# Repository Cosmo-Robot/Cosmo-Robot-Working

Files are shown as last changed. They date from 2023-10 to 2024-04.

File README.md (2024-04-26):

<h1>Cosmo Robot</h1>

<!-- ![Cosmo Robot](Images/in_operation.jpg) -->
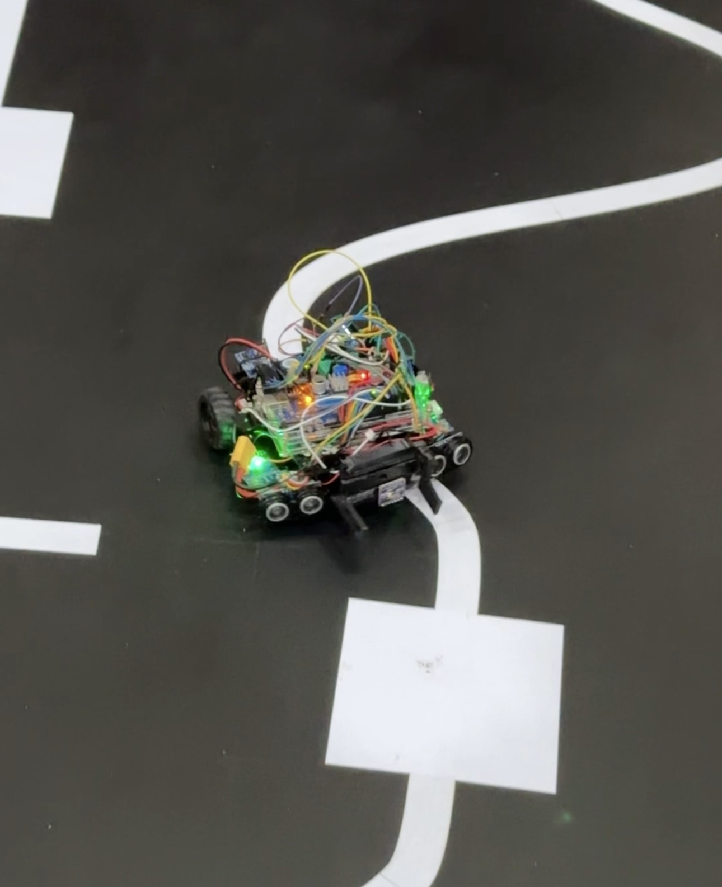
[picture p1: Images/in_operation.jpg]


<h2>Project Summary</h2>

  <p>This project was based on Arduino Mega 2560 and developed for the robot competition held under the Semester 3 module EN2533: Robot Design and Competition. "Cosmo" robot is designed to showcase various capabilities, including precise line following, obstacle avoidance during line following, navigating ramps at 20 - 30 degrees, interacting with objects using a mechanical arm, sound sensitivity, color detection, and maze-solving capabilities. Additionally, it was programmed to avoid other robots in the arena such as the guard robot, on its way to the final destination.</p>

https://github.com/Cosmo-Robot/Cosmo-Robot-Working/assets/111054736/55ebefc1-eb35-40b0-912c-31b81b9e3f68

  <h2>Features</h2>

  <ul>
      <li>Precise line following.</li>
      <li>Obstacle avoidance during line following.</li>
      <li>Ramp navigation (20 - 30 degrees).</li>
      <li>Mechanical arm for interacting with objects.</li>
      <li>Sound sensitivity.</li>
      <li>Color detection.</li>
      <li>Maze solving capabilities.</li>
      <li>Avoiding other robots (Guard Robot).</li>
  </ul>

  <h2>Components Used</h2>

  <ul>
      <li>Arduino Mega 2560.</li>
      <li>Aptinex Reykha IR array and additional IR sensor modules.</li>
      <li>100RPM N20 motors.</li>
      <li>L298 motor driver.</li>
      <li>HY-SRF05 ultrasonic sensors.</li>
      <li>VL53L0X Time-Of-Flight (TOF) sensor.</li>
      <li>TCS3472 RGB color sensor.</li>
      <li>Sound (decibel) sensor.</li>
      <li>3D printed mechanical arm with MG90 metal servo motor.</li>
  </ul>

  <h2>Design Process</h2>

  <ul>
    <li>VS Code and Arduino IDE for programming the robot in C++ language.</li>
    <li>Blender and SOLIDWORKS for robot structure and chassis design.</li>
  </ul>

 <h2>Capable Tasks of the Robot </h2>

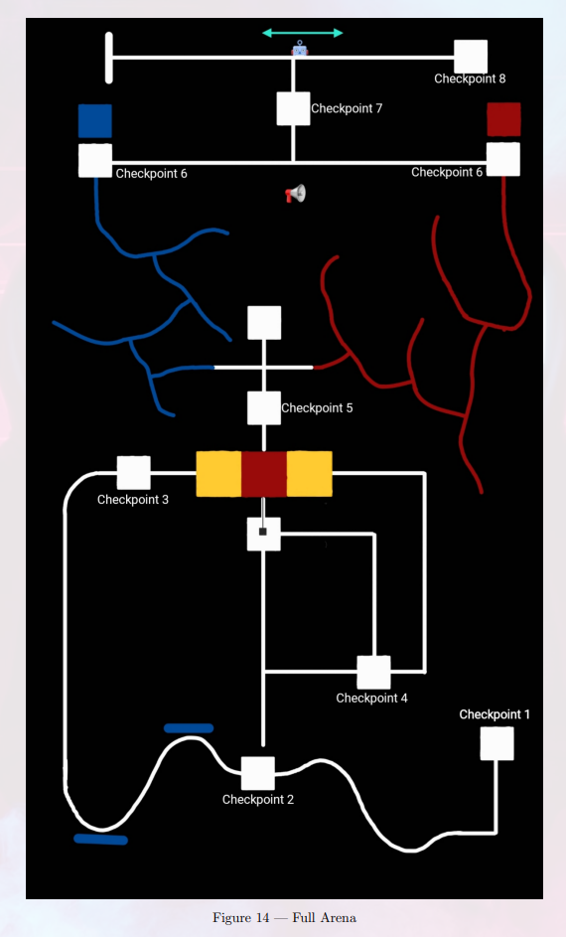
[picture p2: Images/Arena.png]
  

1. Robot will commence it's journey from the designated starting location.
2. If you are unable to complete the task by starting from the designated starting location,
you can start from a checkpoint that is not the designated starting checkpoint with a
penalty.
3. While following the line, the robot shouldn’t collide with any object that isn’t specifically
mentioned in the document.
4. When the robot is navigating from checkpoint - 3 to checkpoint - 4, it must go over the
bridge section and follow the line afterward. There will be a line on the bridge, as well.
5. You can use any mechanism to find the path to reach checkpoint - 5.
6. Pick and place the colored box in the relevant colored space.
7. The robot should freeze when sounds emit from the sound tower.
8. The robot shouldn’t collide with the guard robot.
9. The game is considered finished when the robot completes all six sub tasks, sequentially.

<h2> Game Field (Arena) Specifications </h2>

1. The game arena is characterized by dimensions of 8 feet by 8 feet as shown in figure 14.
2. Within the arena, you will find two sections dedicated to line following, obstacles avoiding,
motion with a buzzer’s sound, a bridge, a robot guard moving section, a designated starting
point, and a specified stopping point.
3. The area designated for line following and obstacles avoiding is marked by white lines, 30
mm in width, on a non-reflective matte black surface.
4. The square boxes (which may not always be positioned at the center) are 5 cm by 5 cm
in size.
5. White squares and colored squares, located on the floor are 15 cm by 15 cm in size.
6. The wall/obstacle has a height of 10 cm and is colored white.
7. Specific dimensions for the bridge section are included in the figure 12 (length measurements are in centimeters ).
8. The wording ”checkpoint X” will not be on the arena. They are shown in the figures just
for understanding purposes, only.

<h2>Robot Specifications </h2>

1. Autonomous Operation: The robot must operate entirely autonomously. Once the
robot initiates its actions, team members are prohibited from making any contact with it.
2. Robot Dimensions: The robot’s dimensions should enable it to fit comfortably within a
250mm x 250mm box (length x width). There are no height restrictions. The robot must
be started using a single onboard switch. Teams may use separate switches for restarting
and for starting from checkpoints, which must be presented to the judges prior to the run.
3. Stability Requirement: The robot must demonstrate stability and stand independently
at the starting zone when the race begins. Failure to meet this criterion will result in
disqualification.
4. Expanding Mechanism: The robot is allowed to expand during its run as long as no
damage is inflicted on the arena. It is strictly prohibited to leave behind any parts or marks
while moving within the arena. Non-compliance will lead to potential disqualification for
the team.
5. Unity of the Bot: The robot cannot split into multiple units during gameplay. Any
machines or units that are in contact with each other or are within the start zone will be
considered as a single entity.
6. Use of Components: Teams are permitted to utilize pre-made microcontroller boards
and sensor kits. However, the incorporation of wireless modules, ready-made Lego kits,
or similar assemblies are not allowed. The use of off-the-shelf kits is prohibited.
7. Simple Starting Procedure: The robot’s starting procedure should be straightforward
and devoid of any manual force or directional impuls
  
  <h2>Contributing</h2>

  <p>Feel free to contribute to the project by submitting bug reports, feature requests, or pull requests. Your contributions are highly appreciated!</p>

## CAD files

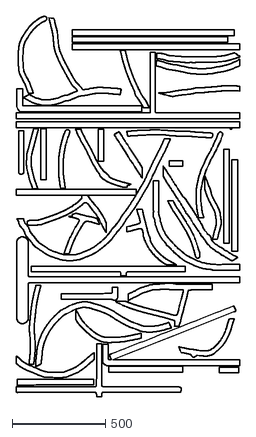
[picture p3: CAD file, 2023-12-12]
Physical Structure Design/Arena.dxf
1200.0 x 2040.8

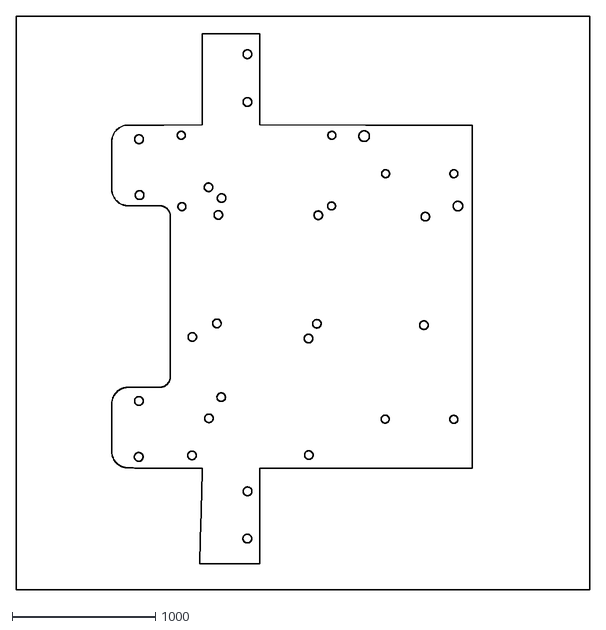
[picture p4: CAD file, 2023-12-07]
Physical Structure Design/Bottom_Panel.dxf
4000.0 x 4000.0

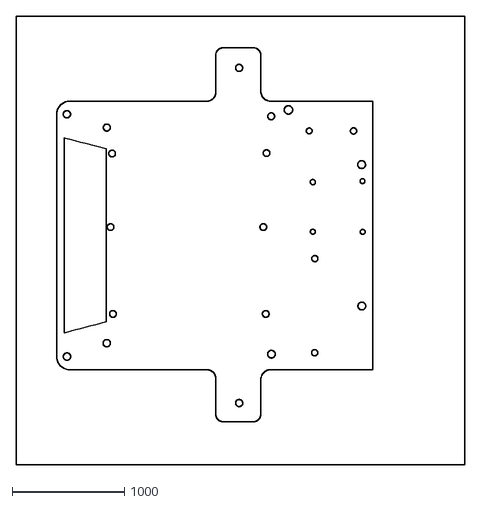
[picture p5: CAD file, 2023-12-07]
Physical Structure Design/Top_Panel.dxf
4000.0 x 4000.0

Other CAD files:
Evaluations/Exercises/Exercise 3/Robot.SLDDRW

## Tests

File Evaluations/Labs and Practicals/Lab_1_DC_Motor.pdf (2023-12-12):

Department of Electronic and Telecommunication Engineering, University of Moratuwa

EN2532 Robot Design and Competition Laboratory Sheet-Practical No: 1

Indexes: 210069F,210174X,210258J,210542B | | | Date: 07 10 2023 | | / | /………
Name: Cosmo | | | Group No: 6 | |
1. What does PWM stand for? Pulse Width Modulation
2. Main parameters to consider generating a PWM? Frequency Duty cycle Resolution
3. Describe the importance of selecting the PWM Frequency The PWM frequency influences the motor sound and the power transistor's switching speed. The human ear can hear 20Hz - 20000Hz range and typically frequencies above 16kHz is not audible. So, it should be selected to be greater than 16kHz. As the motor actually turns on and off at the PWM frequency, if that frequency is above the human audible range (at least above 16kHz), humming sounds generated can be reduced.
4. What will happen when we change the PWM Duty cycle? The speed of the motor changes proportionally to the duty cycle of the PWM signal.
5. What are the two type encoders? Relative encoders, Absolute encoders

6. Why closed loop designs are heavily used in motor controlling Because it gives the ability to regulate the motor parameters such as motor speed, torque and direction of rotation etc. by enabling some sort of intelligence in the system to enhance the system stability.
7. List down the modules(sensors) which can be used to get following feedbacks from a DC motor
a. Rotation speed Encoders, Stroboscopes, Tachometers
b. Direction of rotation Encoders (with two outputs with phase offset)
c. Torque Strain-Gauge sensors
8. If the PWM frequency is 5khz and duty cycle resolution is 10bit. Sketch the PWM signal when duty cycle value is set to 511 in a specific micro controller.

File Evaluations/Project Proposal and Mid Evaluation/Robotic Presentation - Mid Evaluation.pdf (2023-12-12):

# Team Cosmo

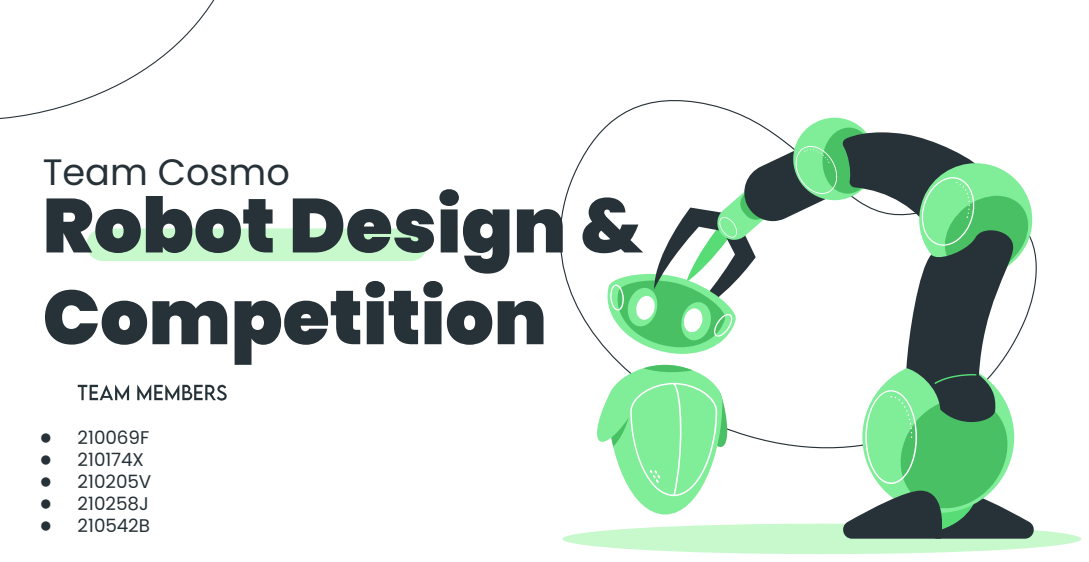
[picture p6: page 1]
Robot Design & Competition

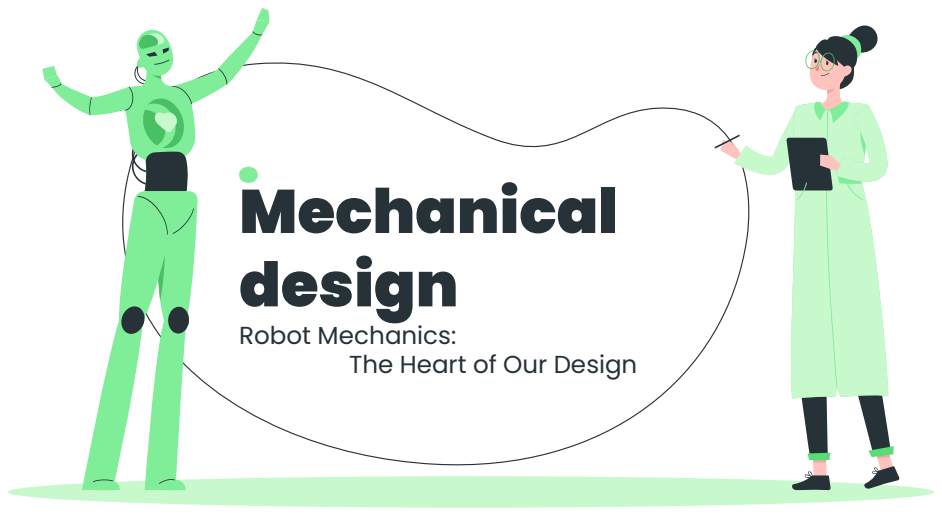
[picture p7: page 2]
Mechanical design; Robot Mechanics:

The Heart of Our Design

# Mechanical design

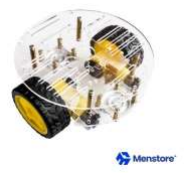
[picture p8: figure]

### 2 wheel design

robot design offers
greater agility and
simplicity, reducing cost
and complexity
compared to four-wheel
designs with wheel
encoders.

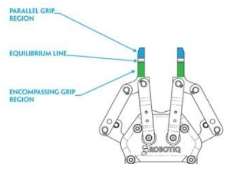
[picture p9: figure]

### Mechanical arm

Mechanical arms on two-wheel robots enable precise manipulation, enhancing
adaptability for various
tasks, making them
preferable.

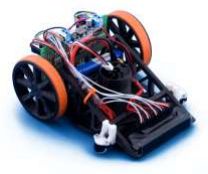
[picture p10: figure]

### 2 supporting wheels

Our 2-wheel robot
design features 2 front
supporting wheels,
preventing collisions
during the slope-climbing phase.

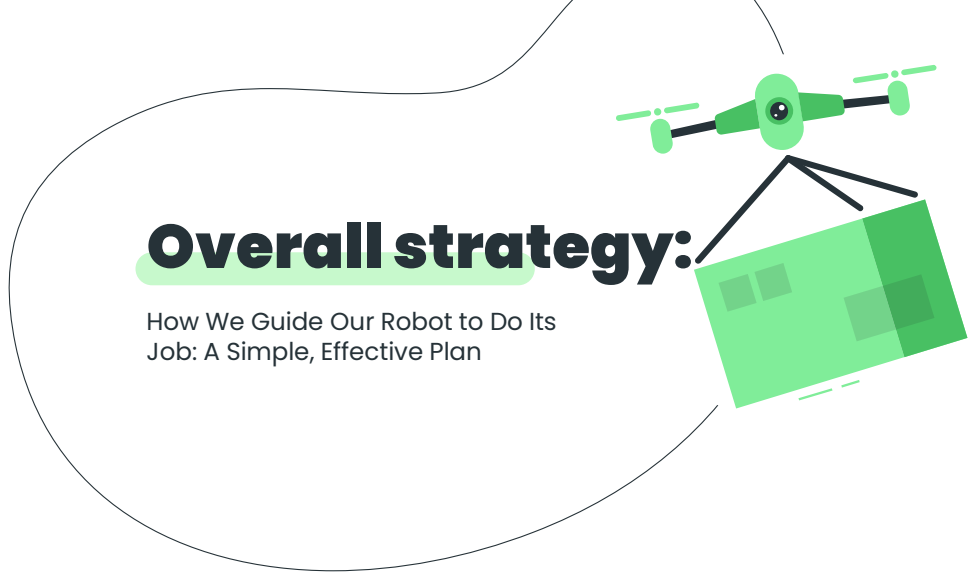
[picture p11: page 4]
Overall strategy:

How We Guide Our Robot to Do Its
Job: A Simple, Effective Plan

# Overall strategy:

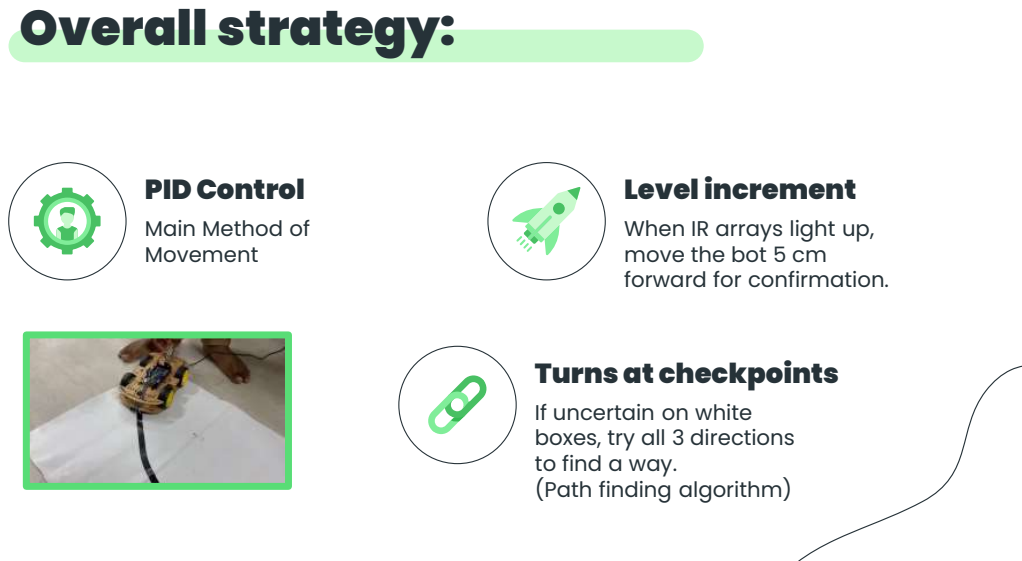
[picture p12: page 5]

PID Control
Main Method of
Movement

Level increment
When IR arrays light up,
move the bot 5 cm
forward for confirmation.

Turns at checkpoints
If uncertain on white
boxes, try all 3 directions
to find a way.
(Path finding algorithm)

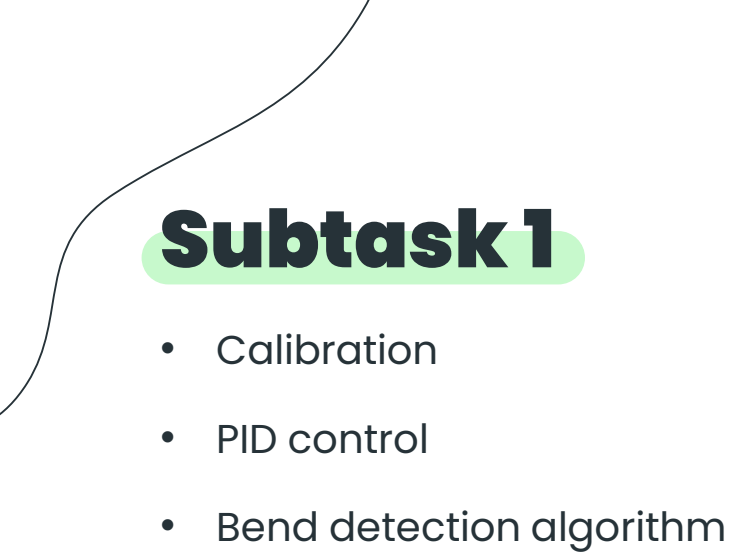
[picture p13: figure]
• Calibration; • PID control; • Bend detection algorithm; Subtask 1
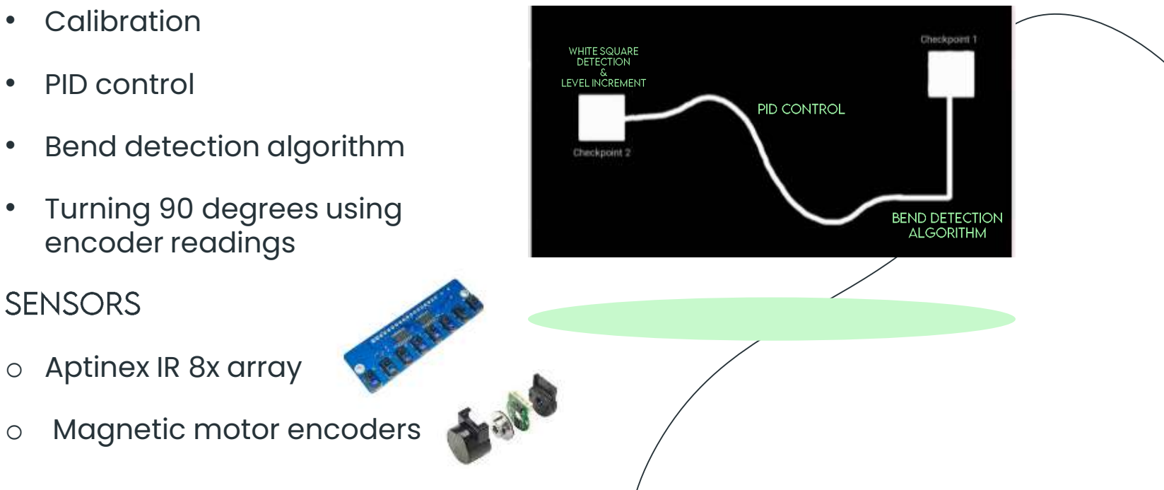
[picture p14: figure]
• Turning 90 degrees using encoder readings; • Aptinex IR 8x array; • Magnetic motor encoders

- PID control

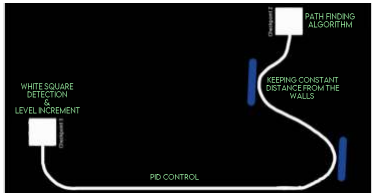
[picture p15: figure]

- Distance sensors at the front to detect the walls
- Distance sensors at the side to keep a constant distance from walls
- Sharp IR sensors
- Ultrasonic sensors/ToF(Time of Flight) sensors

# Subtask 2

• Turning off all non-using sensors; • Angle measuring sensors to move straight on the ramp + wheel encoders for straight movements; Subtask 3 - A
• Using IR array readings in case the robot moved out of the ramp; • Gyroscope (MPU6050)

# Subtask 3 - B


- Algorithm to detect T junction
- Use predefined lengths to move to desired locations
- Mechanical arm to grab the object (which can slide up at idle)
- Grabbing the object and pulling back with the arm, travelling across pre-defined bends
- Sharp IR sensor
- Servo based joints

• Cross junction detection algorithm; • Distance sensor to identify the box and color sensor to scan color; • Node tree algorithm to traverse through the maze; Subtask 4
• Analog IR readings to detect blue and red lines; • Unloading the load using predefined lengths (encoder readings); • Home-made color sensor (LEDs and LDR)

• Sound sensor to trigger movements; • Deciding the direction to turn by pre-chosen color; • Bend detection algorithm; • Sound sensor; Subtask 5

• Front sharp IRs to detect the movement direction of the guard robot; Subtask 6

- Bend detection
- Sharp-IR sensors

# Task delegation

Yasiru Mechanical Design, Maze Traversal and Navigation; Hasitha Mechanical Arm design and implementation, Algorithm development
Linuka Sensor implementation, simulation, Documentation and Reporting; Circuit implementation, Algorithm refinements, Troubleshooting and Debugging; Lasith Algorithm development, PCB design, Battery and Power Management

### Kavindu

Thanks!

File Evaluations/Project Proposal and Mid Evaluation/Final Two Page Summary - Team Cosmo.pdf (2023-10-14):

# Two Page Summary

Team Name: Cosmo

## 1 Overall Strategy

### 1.1 Sub Task 01

Our robot relies on a precise IR sensor panel comprising eight transmitter and receiver pairs to track a white line on a black surface. The middle two sensors detect the white line, while the other three sensors on the left monitor the left side, and the remaining sensors on the right monitor the right side. Using a PID control algorithm, our robot adjusts motor speeds based on sensor inputs, ensuring smooth navigation back to the white line and we utilize magnetic encoders to navigate 90-degree bend with precise accuracy.

### 1.2 Sub Task 02

This task is accomplished through the use of Sharp IR sensors. If two sensors at the front side of the bot detect the wall, the bot is gently turned to maintain a consistent distance between the wall and the ultrasonic sensor on the corresponding side of the bot (either left or right based on the detected wall side). This adjustment continues until the bot realigns with the line. The remaining adjustments are handled by the PID control algorithm.

### 1.3 Sub Task 03

Firstly, unnecessary sensors are turned off to conserve torque. We use a gyroscope to measure the angle, ensuring the robot moves straight on the ramp in the absence of the line. When the robot reaches the top of the ramp, an IR array can detect whether the robot has moved out of the platform, while encoders maintain the straight movement. The algorithm guides the robot to the checkpoint 4 through known bends.
After reaching checkpoint 4, the algorithm detects the T-junction and utilizes predefined distances to navigate to specific locations. i.e., after reaching the T-junction, the robot takes a right turn and moves forward for a known distance with the assistance of IR sensors until it reaches the object. Once the object is within range, the mechanical arm grabs it and pulls back approximately 55 cm before releasing it. Subsequently, the robot moves backward until it detects the junction and then takes a right turn, making necessary adjustments, and continues moving until it reaches checkpoint 5.

### 1.4 Sub Task 04

We implement a cross-junction detection algorithm to identify cross-junctions, and the robot recognizes boxes using distance sensors. Using a color sensor, the robot can scan and detect colors. Upon returning to the cross-junction, the robot determines a suitable path based on the identified color using the color sensor. We employ a node tree algorithm to traverse through the maze and the robot uses analog IR readings to detect blue and red lines. Traversal stops when the white box is detected. To unload the colored box, the robot moves forward a known distance and then returns to its original position.

### 1.5 Sub Task 05

The robot is equipped with a sound sensor to trigger the movements. It determines the direction to turn based on a pre-selected color. When a sound is detected using the sound sensor, the robot freezes. Conversely, in the absence of sound, the robot moves forward. Using this approach, the robot takes turns based on bend detection algorithms and continues moving until it reaches checkpoint 7.

1

### 1.6 Sub Task 06

The robot will wait at the checkpoint until the guard robot’s movements are detected by the distance sensors. It utilizes the trigger time of the two sensors to identify the direction in which the guard robot moved. After detecting that the guard robot moved to the left side, the robot initiates its movements. It continues moving until a junction is encountered, then takes a right turn and moves until it reaches the final destination.

## 2 Robot Mechanical Design


Figure 1: Mechanical Arm


Figure 2: Two Wheel Design and Two Supporting Wheels

## 3 Task Delegation

- B.Y.N. Basnayake - Mechanical Design, Maze Traversal and Navigation
- M.M.H.H.B. Gallella - Mechanical Arm design and Implementation, Algorithm Development
- H.L.N.B. Haputhanthri - Algorithm Development, PCB design, Battery, and Power Management
- R.M.K.C. Jayathissa - Circuit Implemntation, Algorithm Refinements, Troubleshooting and Debugging
- R.M.L.H. Ratnayake - Sensor Implementation, Simulation, Documentation and Reporting

2

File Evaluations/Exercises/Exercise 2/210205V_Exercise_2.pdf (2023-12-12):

Index:210205V
Team: Cosmo
Module: EN2533
Exersise 2

## The Arduino Mega 2560 Board

The Arduino Mega 2560 Board is a very powerful board that is a versatile platform for electronics and microcontroller projects. Let's explore its key features and functions.


### 1. Power Supply:

The power supply in the Arduino Mega 2560 Board is responsible for providing stable voltage and current to the board and its connected components. It primarily comprises a voltage regulator and a power connector.

- Voltage Regulator: At the core of this subsystem is the voltage regulator, often the LM7805. This component is crucial for regulating the input voltage, typically ranging from 7V to 12V, down to a stable 5V supply. This stable voltage ensures that the microcontroller unit (MCU) and other components operate reliably.
- Power Connector: The power connector, including the power jack and Vin pin, serves as the interface for connecting external power sources. Users can connect batteries or external power supplies to these connectors.

### 2. Microcontroller Unit (MCU):

The MCU subsystem is the heart of the Arduino Mega 2560 Board and is responsible for executing user programs. At its core is the ATmega2560 microcontroller.

ATmega2560 Microcontroller: This powerful microcontroller is equipped with a wide range of digital and analog I/O pins, generous program memory (Flash), SRAM, and EEPROM. Its robust processing capabilities make it suitable for various applications. It is responsible for executing user-written code, processing inputs, and generating outputs.

### 3. Communication Interfaces:

Effective communication with external devices and peripherals is facilitated by the communication interfaces subsystem. It encompasses multiple components that enable seamless data exchange.
- USB Interface: The board features a USB-to-Serial converter, often the Atmega16U2, which acts as a bridge between the USB connection and the microcontroller. This component facilitates USB communication between the Arduino and a computer, allowing users to program and monitor the board.
- Serial Ports: The Arduino Mega 2560 includes multiple hardware UART ports, offering reliable serial communication capabilities. These ports are often used for communication with various external devices, such as sensors, displays, or other microcontrollers.

### 4. Various Peripheral Components:

- Crystal Oscillator: A crystal oscillator provides precise clock signals to the MCU, ensuring accurate timing for program execution.
- LEDs: Light Emitting Diodes (LEDs) are integrated for visual feedback and debugging. They are often used to indicate the board's status, such as power and activity.
- Reset Button: The reset button serves as a user interface element, allowing users to restart the MCU when needed, which is particularly useful during programming and debugging.

### 5. Pins

- Digital Pins: The Arduino Mega 2560 Board features 54 digital pins, labeled from 0 to 53. They are commonly used for tasks such as reading digital sensors and interfacing with other digital devices.
- Analog Pins: The board includes 16 analog pins, labeled from A0 to A15. These pins are primarily used for reading analog signals from sensors. They can also be configured as digital I/O pins.
- Power Pins: There are 3 types of power pins. 3.3V, 5V, and Vin for an external power source.
- Ground Pins: Ground pins (labeled GND) provide a common reference point for electrical circuits. There are 5 ground pins.
- Reset Pin: The Reset pin is used to reset the microcontroller.
- Communication Pins: It has four hardware UART pins for serial communication
- PWM Pins: The board includes a set of pins that support Pulse Width Modulation (PWM). These pins can generate PWM Signals. The PWM pins are often used for controlling the brightness of LEDs and the speed of motors.
- External Interrupt Pins: There are a total of six external interrupt pins. These pins allow the board to react to external events by triggering an interrupt service routine.

Resources: https://docs.arduino.cc/resources/datasheets/A000067-datasheet.pdf

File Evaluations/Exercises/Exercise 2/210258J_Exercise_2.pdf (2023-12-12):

# Arduino MEGA 2560

210258J - R.M.K.C. Jayathissa - Team Name: Cosmo

The Arduino Mega 2560 is a powerful development board designed for extensive applications. It features the ATmega2560 microcontroller running at 16 MHz and offers 54 digital I/O pins, 16 analog inputs, 4 UARTs (hardware serial ports), a USB connection, power jack, ICSP header, and a reset button. Widely utilized in projects such as robotics and automation, its generous memory, diverse I/O capabilities, and strong community backing make it a top choice among electronics enthusiasts and developers.


Figure 1: Arduino MEGA 2560 Rev3

## 1 Micro Controller Unit (MCU)

The Arduino microcontroller unit (MCU) is the brain behind Arduino boards, responsible for executing user programs. In the Arduino Mega 2560, the core MCU is the ATmega2560. It processes instructions, enabling the board to interact with various components, making it versatile for a wide range of projects.

### 1.1 ATmega2560 Microcontroller

The ATmega2560 microcontroller is a key component in the Arduino Mega 2560 board. It is an 8-bit microcontroller based on the AVR RISC architecture. Running at a clock speed of 16 MHz, the ATmega2560 offers 256 KB of flash memory for program storage, 8 KB of SRAM for data storage, and 4 KB of EEPROM for non-volatile data storage.
This microcontroller provides 54 digital input/output pins, 16 analog inputs, and multiple communication interfaces, including UART, SPI, and I2C. Its robust capabilities make it suitable for a wide range of applications, from robotics and automation to data acquisition and control systems.

## 2 Power Supply

### 2.1 External Power Supply

This option allows users to connect an external power source within the specified voltage range, enabling the board to function without relying on USB power.

1

### 2.2 Voltage Regulator

The Arduino board has a built-in voltage regulator that keeps the voltage stable, ensuring consistent power to the board’s components. It regulates the incoming power supply to the required voltage for smooth operation.

## 3 Communication Interfaces

### 3.1 USB Interface

The Arduino board has a built-in USB-to-serial converter (ATmega16U2) for programming and computer communication via USB.

### 3.2 Serial Ports

Multiple UART ports enable easy serial communication with external devices, enhancing data exchange capabilities.

## 4 Input and Output Peripherals

### 4.1 Analog Input/Outputs

- Analog Pins - The Arduino board has 16 analog pins, labeled from A0 to A15 for reading continuous voltage signals from sensors.
- PWM Pins - With 15 PWM (Pulse Width Modulation) pins, the board can control devices like motors and LEDs with varying intensity or speed.

### 4.2 Digital Input/Outputs

The Arduino Mega 2560 Board provides 54 digital pins, labeled from 0 to 53 primarily used for reading digital sensors and interfacing with other digital devices.

## 5 Other Peripheral Components

### 5.1 Crystal Oscillator

The crystal oscillator delivers accurate clock signals to the MCU, guaranteeing precise timing for program execution.

### 5.2 LEDs (Power LED, Tx and Rx LEDs etc.)

The LEDs integrated into the Arduino Mega 2560 board serve as vital indicators, displaying essential information such as power status, board activity, and debugging feedback

### 5.3 Reset Button

This button on the Arduino board allows users to restart the microcontroller, enabling the board to return to its initial state and initiate new program uploads or debugging sessions.

References :
(https://scholar.ppu.edu/bitstream/handle/123456789/638/1.pdf?sequence=3&isAllowed=
y) (https://scholar.ppu.edu/bitstream/handle/123456789/638/1.pdf?sequence=3&isAllowed=y)
(https://docs.arduino.cc/resources/datasheets/A000067-datasheet.pdf)

2

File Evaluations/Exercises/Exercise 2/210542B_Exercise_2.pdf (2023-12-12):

## Arduino Mega 2560: Subsystems, Peripheral Circuitry, and Components

210542B - Ratnayake R.M.L.H.

## 1 Introduction

Arduino Mega 2560 is a powerful micro-controller board in the Arduino family that is widely used in robotics among with many other fields. With main focus to the Rev3 edition of the board, this report discusses about the different subsystems present in the board along with the peripheral circuitry and components.

## 2 Main Subsystems of Arduino Mega 2560

### 2.1 Power Subsystem

The board can be powered in various ways such as through the USB
cable, | power jack or the Vin | in-
put. | Voltage regulators are used to
give the ATmega2560 micro-controller and other components with their required voltage, and a 3.3V output.

The Arduino board has 3.3V, 5V pins to provide power to the externally connected components along with 5 ground (GND) pins.


Connector | Voltage Range | Component Used
USB Vin PWRIN (DC jack) | 4.8V - 5.5V 5V 7V - 12V | -LMV358LIST-A.9 Op-Amp SPX1117M3-L-5-0 Regulator

### 2.2 Communication Subsystem

ATmega16U2

This chip acts as an interface between the ATmega2560 and the USB input signals. It is a USB-to-Serial converter acting as a bridge between the USB port of the computer and the serial ports of the micro-controller. It enables the user to program the micro-controller easily and get data back from the board as well.

I2C Ports

In Arduino Mega2560, pins 20 and 21 act as I2C (Inter-Integrated Circuits) pins. Multiple I2C devices can be simultaneously connected to these ports to communicate using the I2C protocol. LCD displays are one example.

1

UART Ports

Arduino Mega2560 consists of 4 UART (Universal Asynchronous Receiver/ Transmitter) serial ports. These ports enables to communicate with some external devices like GPS and RFID modules.

SPI Ports

Arduino Mega2560 has 4 SPI (Serial Peripheral Interface) pins, 50, 51, 52, and 53, for quicker communication with peripheral devices within short distances.

### 2.3 Micro-Controller Unit (MCU)

ATmega2560

ATmega2560 micro-controller sits as the core of all performances of the board. It works up to 16 MIPS at 16MHz clock speed (which is provided by a separate crystal oscillator on the board) and consists of 256KB ROM, 4KB EEPROM, 8KB SRAM and 32 x 8 general purpose registers.

Crystal Oscillator

A 16MHz crystal oscillator is fixed in the board to provide the micro-controller with accurate clock signals to work properly.

### 2.4 Input Output (I/O) Subsystem

The Arduino Mega2560 board comprises with 54 digital I/O pins of which 15 are capable of generating PWM signals, and 16 analog pins.

Other than that, there are 6 interrupt pins, 2, 3, 18, 19, 20, 21. When a peripheral connected to these pins triggers an interrupt, the processor will immediately stops whatever it is currently doing an starts processing the interrupt signal.

### 2.5 Other Components

LEDs

Three types of LEDs are visible in Arduino Mega2560 board, namely the power LED, two Tx/ Rx LEDs, and the LED on pin 13.

RESET Button

By pressing this button, the program that is running on the micro-controller can be reset to its beginning.

## References


https://docs.arduino.cc/resources/datasheets/A000067-datasheet.pdfhttps://www.electronicshub.org/arduino-mega-pinout/

2

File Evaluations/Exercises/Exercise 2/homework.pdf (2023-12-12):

- Study the Arduino Mega 2560 Board and describe the functionality of its peripheral circuitry
➢Identify the subsystems
➢Explain the purpose of different electronic components inside each subsystem
Submit a report (pdf): page limit 2 (no cover page needed)

# Homework




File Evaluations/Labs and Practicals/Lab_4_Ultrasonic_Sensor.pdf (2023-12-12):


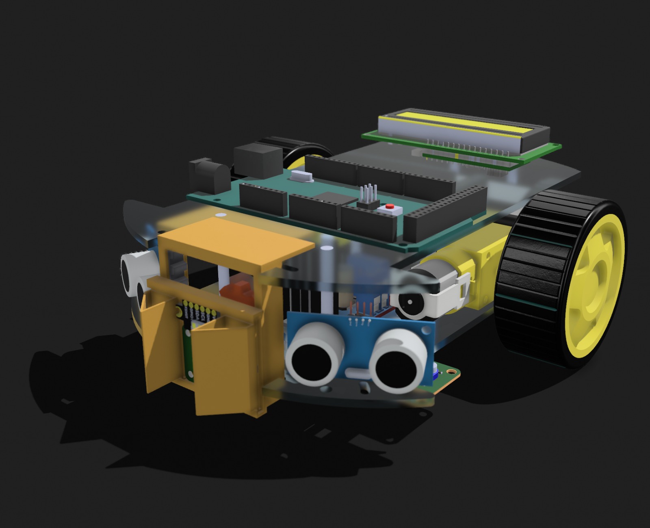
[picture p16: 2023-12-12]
Evaluations/Exercises/Exercise 3/Robot 3D.jpg

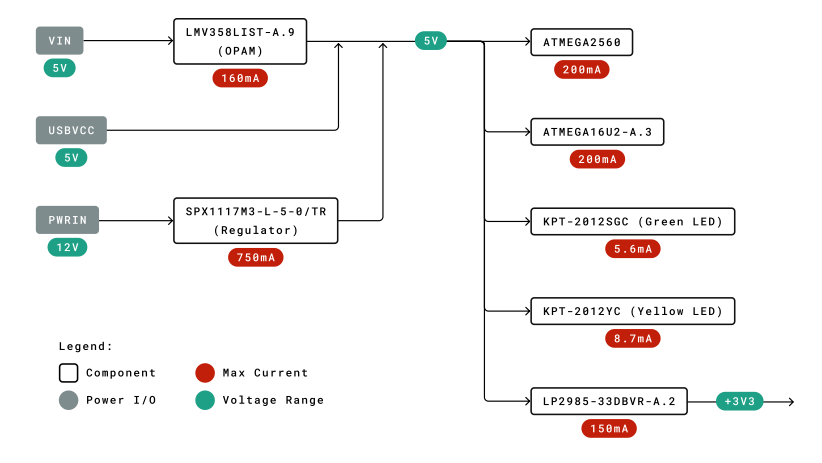
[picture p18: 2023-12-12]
Evaluations/Exercises/Exercise 2/power.png

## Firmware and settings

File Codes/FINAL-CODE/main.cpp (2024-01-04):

//////////////////////////////////////////////////////////////////////////////////////////////////////////////////////////////////////////////////
//Creator:  Team Cosmo
//members: 1)Yasiru Basnayake
//         2)Kavindu Jayathissa
//         3)Lasith Haputhanthri
//         4)Linuka Ratnayake
//         5)Hasitha Gallella
//////////////////////////////////////////////////////////////////////////////////////////////////////////////////////////////////////////////////

#include <Arduino.h>
#include <EEPROM.h>
#include <Servo.h>
#include <Adafruit_I2CDevice.h> 
#include <U8g2lib.h> // include u8g2 library
#include <Wire.h>
#include "Adafruit_TCS34725.h"

// Header guard to prevent multiple inclusions
#include "line follow/lineFollow.h"
#include "detections/detections.h"
#include "sensors/sensors.h"
#include "level management/levelManage.h"

/////////////////////////////////Object Definitions///////////////////////////////////////////////////////////////////////////////////////////////

#ifdef U8X8_HAVE_HW_SPI
#include <SPI.h>
#endif
#ifdef U8X8_HAVE_HW_I2C
#include <Wire.h>
#endif

U8G2_SH1106_128X32_VISIONOX_F_HW_I2C u8g2(U8G2_R0, /* reset=*/U8X8_PIN_NONE);

Servo arm; // create servo object to control a servo

Adafruit_TCS34725 tcs = Adafruit_TCS34725();

/////////////////////////////////Definitions///////////////////////////////////////////////////////////////////////////////////////////////

#define Debug_led 13

#define trigPin 6 // define trig pin 6 and echo pin 7
#define echoPin 7

#define calibration 7 // pushbutton input for calibration

#define buzzer_pin 8 // pin for buzzer

#define right_bend_sensor 9 // pin for right bend sensor

#define IR_ARRAY_LENGTH 12 // IR_array 8 space empty array

#define ENR 3 // define right motor enable pin is 3 and left 2
#define ENL 2

#define Motor_Right_Forward 28
#define Motor_Right_Backward 24
#define Motor_Left_Forward 22
#define Motor_Left_Backward 26

#define RIGHT_MOTOR 1 // Motor and Direction Definitions
#define LEFT_MOTOR 2
#define FORWARD 1
#define BACKWARD 2

#define SOUND_SENSOR A10 // Sound sensor
#define SOUND_THRESHOLD 300
#define SOUND_WAIT_TIME 500 // milliseconds
#define SOUND_LED 13

#define SENSOR_LEFT 1 // Ultrasonic sensors
#define SENSOR_RIGHT 2

#define SENSOR_LEFT_TRIG_PIN 32
#define SENSOR_LEFT_ECHO_PIN 34

#define SENSOR_RIGHT_TRIG_PIN 36
#define SENSOR_RIGHT_ECHO_PIN 38

#define MAX_ULTRASONIC_DISTANCE 30 // in centimeters

#define TASK_SWITCH 44 // Task selection switch
#define SWITCH_MSB 45
#define SWITCH_MID_SB 46
#define SWITCH_LSB 47

bool wallVar = true;
// PID parameters for Line Following
double Kp = 8;
double Ki = 0;
double Kd = 7;

// PID parameters for Ultrasonic Wall Following
double UKp = 35;
double UKi = 0;
double Ukd = 20;

int Drive_constant = 200;

// Initialize PID variables
double prevError = 0;
double integral = 0;
double derivative = 0;

// recorrect
int Ir_thresholds[] = {300, 300, 100, 100, 100, 105, 400, 400};

int prev_error_history[] = {0, 0, 0, 0, 0, 0, 0, 0, 0, 0};
int stack_pointer = 0;

int IR_history_count = 0;
int IR_history = 0;
int IR_first_grabbed = 0;

int guard_left = 0;
int guard_right = 0;
int guard_left_prev = 2;
int guard_right_prev = 2;

int count = 0;

int crossCount = 0;

bool pull_box_arm_retract = false;
bool pull_bend = false;

const String LINE_COLOR = "WHITE";
int array_lit_amount = 0;
// Define the size of the array and the EEPROM address to start writing data
const int arraySize = 8;     // Adjust this based on your array size
const int eepromAddress = 0; // EEPROM address where you want to start writing

bool bend_done = false;

bool Switch = 1;

bool bend_start = false;

bool bend_condition = false;

bool boxGrabbed = false;

int now_time = 0;

bool colorBoxGrabbed = false;

String mode = "normal";
String wall_side = "";

String STAGES[] = {"LINE", "WALL", "RAMP", "PULL", "COLOR", "SOUND", "GUARD", "HALT"};
int pointer = 0;

int IR_array[IR_ARRAY_LENGTH];

int Threshold = 100;

int prev_position = 0;
int prev_history_sum = 0;

int x = 0; // bool Switch = 0; //0 for left ; 1 for right;

float ultrasonic_prev_error = 0;

int sound_threshold = 500;

int temp = 0;

int Left_drive = 0;
int Right_drive = 0;

String color_picked = "none";
bool colorBoxPlaced = true;

/////////////////////////////////Function Declarations/////////////////////////////////////////////////////////////////////////////////////

void motor(int , int);
void buzzer_beep();
void wallFollow();

//////////////////////////////////////////////////////////////////////////////////////////////////////////////////////////////////////////////////
/////////////////////////////////////////Setup//////////////////////////////////////////////////////////////////////////////////////////
/////////////////////////////////////////////////////////////////////////////////////////////////////////////////////////////////////

void setup()
{
  // put your setup code here, to run once:

  //begin serial communication
  Serial.begin(115200);
  u8g2.begin();

  if (tcs.begin()) {
    Serial.println("Found sensor");
  } else {
    Serial.println("No TCS34725 found ... check your connections");
    while (1);
  }

  soundCalibrate(); // Calibrate the sound sensor

  // pinmode trig and echo
  pinMode(trigPin, OUTPUT);
  pinMode(echoPin, INPUT);

  pinMode(buzzer_pin, OUTPUT);

  pinMode(Motor_Right_Forward, OUTPUT);
  pinMode(Motor_Right_Backward, OUTPUT);
  pinMode(Motor_Left_Forward, OUTPUT);
  pinMode(Motor_Left_Backward, OUTPUT);
  
  pinMode(right_bend_sensor, INPUT);

  pinMode(calibration, INPUT);

  pinMode(SENSOR_LEFT_ECHO_PIN, INPUT);
  pinMode(SENSOR_LEFT_TRIG_PIN, OUTPUT);
  pinMode(SENSOR_RIGHT_ECHO_PIN, INPUT);
  pinMode(SENSOR_RIGHT_TRIG_PIN, OUTPUT);

  pinMode(TASK_SWITCH, INPUT);
  pinMode(SWITCH_MSB, INPUT);
  pinMode(SWITCH_MID_SB, INPUT);
  pinMode(SWITCH_LSB, INPUT);

  pinMode(12, INPUT);

  //reading the IR thresholds from EEPROM
  for (int i = 0; i < IR_ARRAY_LENGTH; i++)
  {
    byte temp = 0;
    // Ir_thresholds[i] = EEPROM.read(i)*4;
    EEPROM.get(i, temp);
    Ir_thresholds[i] = temp;
  }

  //for motor initialization
  motor(RIGHT_MOTOR, FORWARD);
  motor(LEFT_MOTOR, FORWARD);

  modeSelect(); // Select the mode of operation
}

//////////////////////////////////////////////////////////////////////////////////////////////////////////////////////////////////////////////////
/////////////////////////////////////////Loop//////////////////////////////////////////////////////////////////////////////////////////
/////////////////////////////////////////////////////////////////////////////////////////////////////////////////////////////////////

void loop()
{

  // Automatically increment task after detecting a white square.
  levelManage();

  if (Switch != 1)
  {
    Left_drive = 0;
    Right_drive = 0;
  }

  //signalling the speed to the motors
  analogWrite(ENL, Left_drive);
  analogWrite(ENR, Right_drive);

  // put your main code here, to run repeatedly:
  if (digitalRead(calibration) == 1){calibrate();}
}

//////////////////////////////////////////////////////////////////////////////////////////////////////////////////////////////////////////////////
/////////////////////////////////////////FUNCTIONS//////////////////////////////////////////////////////////////////////////////////////////
/////////////////////////////////////////////////////////////////////////////////////////////////////////////////////////////////////

///////////////////////////Motor direction choosing///////////////////////////////////////////

void motor(int motor, int direction)
{
  if (motor == RIGHT_MOTOR)
  {
    if (direction == FORWARD)
    {
      digitalWrite(Motor_Right_Forward, HIGH);
      digitalWrite(Motor_Right_Backward, LOW);
    }
    else if (direction == BACKWARD)
    {
      digitalWrite(Motor_Right_Forward, LOW);
      digitalWrite(Motor_Right_Backward, HIGH);
    }
  }
  else if (motor == LEFT_MOTOR)
  {
    if (direction == 1)
    {
      digitalWrite(Motor_Left_Forward, HIGH);
      digitalWrite(Motor_Left_Backward, LOW);
    }
    else if (direction == BACKWARD)
    {
      digitalWrite(Motor_Left_Forward, LOW);
      digitalWrite(Motor_Left_Backward, HIGH);
    }
  }
}

///////////////////////////For debugging ///////////////////////////////////////////

void buzzer_beep()
{
  digitalWrite(buzzer_pin, 1);
  delay(100);
  digitalWrite(buzzer_pin, 0);
}

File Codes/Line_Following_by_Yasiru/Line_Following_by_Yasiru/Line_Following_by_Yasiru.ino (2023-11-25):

// THIS IS FIRST AND SIMPLEST WORKING CODE FOR CALIBERATION AND BEND TAKING

#include <Arduino.h>

#include <LiquidCrystal_I2C.h>

#include <PID_v1.h>

#include <EEPROM.h>

// Define the size of the array and the EEPROM address to start writing data
const int arraySize = 8; // Adjust this based on your array size
const int eepromAddress = 0; // EEPROM address where you want to start writing


// Define PID parameters
double Kp = 7;
double Ki = 1.5;
double Kd = 10;

// Initialize PID variables
double prevError = 0;
double integral = 0;
double derivative = 0;

//recorrect
int Ir_thresholds[] = {300, 300, 100, 100, 100, 105, 400, 400};


// Define the setpoint (center of the line)
double setpoint = 512;

// Initialize PID variables
double input, output;
PID pid(&input, &output, &setpoint, Kp, Ki, Kd, DIRECT);


LiquidCrystal_I2C lcd(0x27,20,4);  // set the LCD address to 0x27 for a 16 chars and 2 line display

//define trig pin 6 and echo pin 7
#define trigPin 6
#define echoPin 7

//pushbutton input for caliberation
#define caliberation 7

//pin for buzzer
#define buzzer_pin 8

bool swich = 1; 

int now_time = 0;

String mode = "normal";

//IR_array 8 space empty array
int IR_array[8];

int Threshold = 100;

//define right motor enable pin is 3 and left 2
#define ENR 3
#define ENL 2

#define Motor_Right_Forward 41
#define Motor_Right_Backward 43
#define Motor_Left_Forward 45
#define Motor_Left_Backward 47

// defines variables
long duration;
int distance;

// bool Switch = 0; //0 for left ; 1 for right;
int x = 0;

void motor(int motor, int direction);
void caliberate();
void buzzer_beep();
void LCD_initial();

void setup() {

  pinMode(buzzer_pin, OUTPUT);

  //pin 8 is buzzer, tur it on and off for 2 quick beeps
  buzzer_beep();
  delay(100);
  buzzer_beep();
  

  lcd.init(); // initialize the lcd 
  // Print a message to the LCD.
  lcd.backlight();

  LCD_initial();

  //pinmode trig and echo
  pinMode(trigPin, OUTPUT);
  pinMode(echoPin, INPUT);

  //Serial begin
  Serial.begin(9600);

  for (int i = 0; i < 8; i++) {
    Ir_thresholds[i] = EEPROM.read(i)*4;
  }

  Serial.print("int IR_thresholds[] = {");
  for (int i = 0; i < 8; i++){
    Serial.print(Ir_thresholds[i]);
    Serial.print(", ");
  }
  Serial.println("};    ");


  pinMode(Motor_Right_Forward, OUTPUT);
  pinMode(Motor_Right_Backward, OUTPUT);
  pinMode(Motor_Left_Forward, OUTPUT);
  pinMode(Motor_Left_Backward, OUTPUT);


  // Initialize the PID controller
  pid.SetMode(AUTOMATIC);
  pid.SetOutputLimits(-255, 255); // Adjust these limits according to your motor driver

  // Start the PID controller
  pid.SetSampleTime(10); // Update the PID every 10ms



  // digitalWrite(Motor_Right_Forward,1);

  motor(1,1);
  motor(2,1);

  pinMode(caliberation, INPUT);
  
}

int temp = 0;

void loop() {

  if (digitalRead(caliberation) == 1){
    caliberate();
  }


  //serial print from A0 to A7
   for (int i = 0; i < 8; i++){
    // Serial.print(analogRead(i));
    // Serial.print(" ");
    if (analogRead(i) > Ir_thresholds[i]){
      temp = 1;}
    else{
      temp = 0;}
     IR_array[i] = temp;

   }

//  for (int i = 0; i < 8; i++){
//    Serial.print(IR_array[i]);
//    Serial.print(" ");
//   }
  // Serial.println(" ");

  int array_lit_amount = IR_array[0] + IR_array[1] + IR_array[2] + IR_array[3] + IR_array[4] + IR_array[5] + IR_array[6] + IR_array[7];
  int left_sum = -4*IR_array[0] -3*IR_array[1] -2*IR_array[2] -1*IR_array[3];
  int right_sum = 1*IR_array[4] +2*IR_array[5] +3*IR_array[6] +4*IR_array[7];
  int position = left_sum + right_sum;

   derivative = position - prevError;

  int PID_constant = position*Kp + Kd * derivative;

  prevError = position;

  
  //Serial.println(position);
  // lcd.setCursor(2,2);
  // lcd.print("The IR weight: ");
  // lcd.print(position);

  int Drive_constant = 50;

  int Left_drive = Drive_constant + PID_constant;
  int Right_drive = Drive_constant - PID_constant;



  if (Left_drive > 255){
    Left_drive = 255;
  }

  if (Left_drive < 0){
    Left_drive = 0;
  }

  if (Right_drive > 255){
    Right_drive = 255;
  }
  
  if (Right_drive < 0){
    Right_drive = 0;
  }

  // lcd.setCursor(0,3);
  // lcd.print("Right: ");
  // lcd.print(Right_drive);
  // lcd.print(" Left: ");
  // lcd.print(Left_drive);

  //end detection
  if (array_lit_amount >= 6){
    swich = 0;
  }

  if (mode == "normal"){
    //bend detection
    if(right_sum >= 9 && left_sum > -4){
      //breaking
      motor(1,0);
      motor(2,0);
      now_time = millis();
      mode = "bend";
      
      lcd.setCursor(3,3);
      lcd.print("Mode: ");
      lcd.print(mode);

    }
  }

  if (mode == "bend"){
    //  if(millis() - now_time < 200){
    //   Left_drive = 0;
    //   Right_drive = 0;
    // }else
    if (millis() - now_time < 800){
      motor(1,1);
      motor(2,1);   
      Left_drive = 40;
      Right_drive = 40;
    }else{
      buzzer_beep();
      motor(1,0);
      motor(2,1);

      Left_drive = 50;
      Right_drive = 60;
      if (array_lit_amount >= 1){
        delay(50);
        array_lit_amount = IR_array[0] + IR_array[1] + IR_array[2] + IR_array[3] + IR_array[4] + IR_array[5] + IR_array[6] + IR_array[7];
        if (array_lit_amount >= 1){

          Serial.print("bend over");
          mode = "normal";
          
          
          lcd.setCursor(3,3);
          lcd.print("Mode: ");
          lcd.print(mode);

          
          motor(1,1);
          motor(2,1);
        }
      }
    }
  }

  
  if (swich == 1){
  analogWrite(ENL,Left_drive);
  analogWrite(ENR,Right_drive);
  }else{
  analogWrite(ENL,0);
  analogWrite(ENR,0);
  }
  
  // analogWrite(ENL,200);
  // analogWrite(ENR,0);

  

  

  //Serial.println(IR_array[2]);
  //Serial.println(IR_array[5]);
  
  // //read the distance from ultrasonic sensor
  // // Clears the trigPin
  // digitalWrite(trigPin, LOW);
  // delayMicroseconds(2);

  // // Sets the trigPin on HIGH state for 10 micro seconds
  // digitalWrite(trigPin, HIGH);
  // delayMicroseconds(10);
  // digitalWrite(trigPin, LOW);

  // // Reads the echoPin, returns the sound wave travel time in microseconds
  // duration = pulseIn(echoPin, HIGH);    
  
  // // Calculating the distance
  // distance= duration*0.034/2;

  // // Prints the distance on the Serial Monitor
  // //Serial.print("Distance: ");
  // //Serial.println(distance);
  
  // if (distance < 8){
  //   analogWrite(ENL,255);
  //   analogWrite(ENR,255);
  //   motor(1,0);
  //   motor(2,0);
  //   delay(100);
  //   analogWrite(ENL,0);
  //   analogWrite(ENR,0);
  // } else {
  //   analogWrite(ENL,00);
  //   analogWrite(ENR,00);
  //   motor(1,1);
  //   motor(2,1);
  // }

}
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

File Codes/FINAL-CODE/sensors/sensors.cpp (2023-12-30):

#include "sensors.h"

///////////////////////////Calibarating IR Thresholds///////////////////////////////////////////

void calibrate()
{

  motor(RIGHT_MOTOR, BACKWARD);
  motor(LEFT_MOTOR, FORWARD);

  // Stop motors when calibrating
  analogWrite(ENL, 255);
  analogWrite(ENR, 255);

  // make sensor_max_values array of length 8 equal to sensor calibration array
  int sensor_max_values[8] = {0, 0, 0, 0, 0, 0, 0, 0};

  // sensor min values array
  int sensor_min_values[8] = {0, 0, 0, 0, 0, 0, 0, 0};

  int now_time_for_calibration = millis();
  Serial.print("now time for calibration: ");
  Serial.print(now_time_for_calibration);
  Serial.print("  millis: ");
  Serial.println(millis());

  while (millis() - now_time_for_calibration < 8000)
  {
    // Serial.println("Caliberating IR");
    digitalWrite(buzzer_pin, 1);

    bool allZeros = true;
    for (int i = 0; i < 8; i++)
    {
      if (sensor_max_values[i] != 0)
      {
        allZeros = false;
        break; // No need to continue checking if we find a non-zero value
      }
    }

    if (allZeros)
    {
      for (int i = 0; i < 8; i++)
      {
        sensor_max_values[i] = analogRead(i);
        sensor_min_values[i] = analogRead(i);
      }
    }

    for (int i = 0; i < 8; i++)
    {
      if (analogRead(i) > sensor_max_values[i])
      {
        sensor_max_values[i] = analogRead(i);
      }
      if (analogRead(i) < sensor_min_values[i])
      {
        sensor_min_values[i] = analogRead(i);
      }
    }
  }
  Serial.print("int IR_thresholds[] = {");
  for (int i = 0; i < 8; i++)
  {
    Serial.print(sensor_max_values[i]);
    Serial.print(", ");
  }
  Serial.print("};    ");
  Serial.print("int IR_thresholds[] = {");
  for (int i = 0; i < 8; i++)
  {
    Serial.print(sensor_min_values[i]);
    Serial.print(", ");
  }
  Serial.print("};    ");

  for (int i = 0; i < 8; i++)
  {
    Ir_thresholds[i] = (sensor_max_values[i] + sensor_min_values[i]) / 2;
  }

  Serial.print("int IR_thresholds[] = {");
  for (int i = 0; i < 8; i++)
  {
    Serial.print(Ir_thresholds[i]);
    Serial.print(", ");
  }
  Serial.println("};    ");

  // save the array to eeprom
  for (int i = 0; i < 8; i++)
  {
    // EEPROM.write(i, byte(Ir_thresholds[i]/4));
    EEPROM.put(i, byte(Ir_thresholds[i]));
  }

  delay(1000);

  digitalWrite(buzzer_pin, 0);

  analogWrite(ENL, 0);
  analogWrite(ENR, 0);

  delay(4000);
}

///////////////////////////Ultrasonic sensor reading///////////////////////////////////////////

int ultrasonicDistance(int sensor)
{
  int distance = 0;
  if (sensor == SENSOR_LEFT)
  {
    digitalWrite(SENSOR_LEFT_TRIG_PIN, LOW);
    delayMicroseconds(2);
    digitalWrite(SENSOR_LEFT_TRIG_PIN, HIGH);
    delayMicroseconds(10);
    digitalWrite(SENSOR_LEFT_TRIG_PIN, LOW);
    distance = pulseIn(SENSOR_LEFT_ECHO_PIN, HIGH) / 2 * 0.034;
  }
  else if (sensor == SENSOR_RIGHT)
  {
    digitalWrite(SENSOR_RIGHT_TRIG_PIN, LOW);
    delayMicroseconds(2);
    digitalWrite(SENSOR_RIGHT_TRIG_PIN, HIGH);
    delayMicroseconds(10);
    digitalWrite(SENSOR_RIGHT_TRIG_PIN, LOW);
    distance = pulseIn(SENSOR_RIGHT_ECHO_PIN, HIGH) / 2 * 0.034;
  }
  return distance;
}


///////////////////////////Updating the IR array elements///////////////////////////////////////////
void readIRArray()
{
  for (int i = 0; i < IR_ARRAY_LENGTH - 4; i++)
  {
    // Serial.print(analogRead(i));
    // Serial.print(" ");
    if (LINE_COLOR == "WHITE")
    {
      temp = analogRead(i) <= Ir_thresholds[i];
    }
    else if (LINE_COLOR == "BLACK")
    {
      temp = analogRead(i) > Ir_thresholds[i];
    }
    // IR_array[IR_ARRAY_LENGTH - 1 - i] = temp;

    // IR_array[i] = temp; // This is correct if pins are connected in order.
    IR_array[i + 2] = temp;

    // This part is needed because the pins are connected not in order.
    // if (i < 8) {
    //     IR_array[i + 2] = temp;
    // }
    // else {
    //     if (i == 8) IR_array[0] = temp;
    //     else if (i == 9) IR_array[1] = temp;
    //     else if (i == 10) IR_array[10] = temp;
    //     else if (i == 11) IR_array[11] = temp;
    // }
  }

  IR_array[0] = 1 - digitalRead(A11);
  IR_array[1] = 1 - digitalRead(A10);
  IR_array[10] = 1 - digitalRead(A9);
  IR_array[11] = 1 - digitalRead(A8);

  // for (int i = 0; i < IR_ARRAY_LENGTH; i++)
  // {
  //   Serial.print(IR_array[i]);
  //   Serial.print(" ");
  // }
  // Serial.println();
}


///////////////////////////Sound Calibration///////////////////////////////////////////
void soundCalibrate()
{
  int now_time = millis();
  int max_sound = 0;
  int min_sound = 1024;
  u8g2.clearBuffer();                 // clear the internal memory
  u8g2.setFont(u8g2_font_ncenB08_tr); // choose a suitable font
  u8g2.drawStr(0, 10, "SOUND CALIBERATING");        // write something to the internal memory
  u8g2.sendBuffer();
  while (millis()-now_time <= 5000){
    int analog_sound_read = analogRead(A13);
    Serial.println(analog_sound_read);
    max_sound = max(analog_sound_read, max_sound);
    min_sound = min(analog_sound_read,min_sound);
  }
  sound_threshold = (max_sound + min_sound)/2;
  Serial.println(sound_threshold);
}

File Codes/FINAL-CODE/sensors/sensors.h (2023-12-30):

// lineFollow.h

#include <Arduino.h>
#include <EEPROM.h>
#include <U8g2lib.h>

// Header guard to prevent multiple inclusions
#ifndef SENSORS_H
#define SENSORS_H

void motor(int motor, int direction);

#ifdef U8X8_HAVE_HW_SPI
#include <SPI.h>
#endif
#ifdef U8X8_HAVE_HW_I2C
#include <Wire.h>
#endif

extern U8G2_SH1106_128X32_VISIONOX_F_HW_I2C u8g2;

// Motor and Direction Definitions
#define RIGHT_MOTOR 1
#define LEFT_MOTOR 2
#define FORWARD 1
#define BACKWARD 2

// Ultrasonic sensors
#define SENSOR_LEFT 1
#define SENSOR_RIGHT 2

#define SENSOR_LEFT_TRIG_PIN 32
#define SENSOR_LEFT_ECHO_PIN 34

#define SENSOR_RIGHT_TRIG_PIN 36
#define SENSOR_RIGHT_ECHO_PIN 38

// pin for buzzer
#define buzzer_pin 8

// ========== LINE_COLOR DEFINITION ==========
extern const String LINE_COLOR;

// IR_array 8 space empty array
#define IR_ARRAY_LENGTH 12
extern int IR_array[IR_ARRAY_LENGTH];

extern int Ir_thresholds[];

extern int temp;

extern int array_lit_amount;

extern int prev_error_history[];
extern int stack_pointer;

extern int Left_drive;
extern int Right_drive;

extern int sound_threshold;

// pin for right bend sensor
#define right_bend_sensor 9

// define right motor enable pin is 3 and left 2
#define ENR 3
#define ENL 2


int ultrasonicDistance(int sensor);
void readIRArray();
void calibrate();
void soundCalibrate();

#endif

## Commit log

2023-10-21 Create "Motor" Library
2023-11-25 Include Sound Sensor Basic Tests
2023-11-26 Create PID.txt added
    testing codes
2023-11-26 PID controls 1st test code added
2023-11-26 New improvement with potentiometers and Switches
2023-11-29 Test Bends and Encoders
2023-12-02 Sound Sensor, Encoders, Folder Structure
    Integrate sound sensor to halt, check encoder readings, and change folder structure
2023-12-03 Reformat the currently working code
2023-12-07 Reformat code drastically
    [Panel-_1.dxf, Panel-_2.dxf]
2023-12-12 Add evaluations files
    [Arena.dxf, Bottom_Panel.dxf, Panel-_1.dxf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]
2023-12-18 Refactor: Split main.cpp into modular files for improved code organization
    This commit separates the codebase for better modularity and maintainability. The main.cpp file has been broken down into smaller, specialized files: detections.h/cpp, levelManage.h/cpp, lineFollow.h/cpp, sensor.h/cpp, enhancing the code structure. This restructuring aims to improve readability, facilitate easier debugging, and enable more straightforward maintenance by isolating specific functionalities into separate modules.
    [FINAL-CODE.cpp, detections.cpp, detections.h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]
2023-12-19 updated the final code
    more shorter and easy to understand. Optimizations applied
    [levelManage.h, lineFollow.cpp, main.cpp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]
2023-12-30 update: code updated up-to getting the bed depending on the color picked
